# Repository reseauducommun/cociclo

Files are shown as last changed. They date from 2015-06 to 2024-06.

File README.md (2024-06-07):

# cociclo
An airborne particles, Carbon Monoxyde (CO), temperature and humidity sensor circuit based on the ESP8266 (Wemos).  One version sends data to mysql and allows for the exploration of visualisations.  The other turns the pollution levels into sound for a participatory walk. 

For more information about the art and activism project : https://artengine.ca/acastonguay

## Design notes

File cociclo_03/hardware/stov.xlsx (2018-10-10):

Stock | 2018-06-12
 | 50 | Wemos
AgitPOV
 | 100 + | plaquettes
 | 40 | batteries
 | 200 | chargeurs lipo
Cociclo
 | 50 | v. 0.3
 | 40 | v.02
 | 4 | v.0.4
 | 8 | MQ-7
 | 35 | DHT11

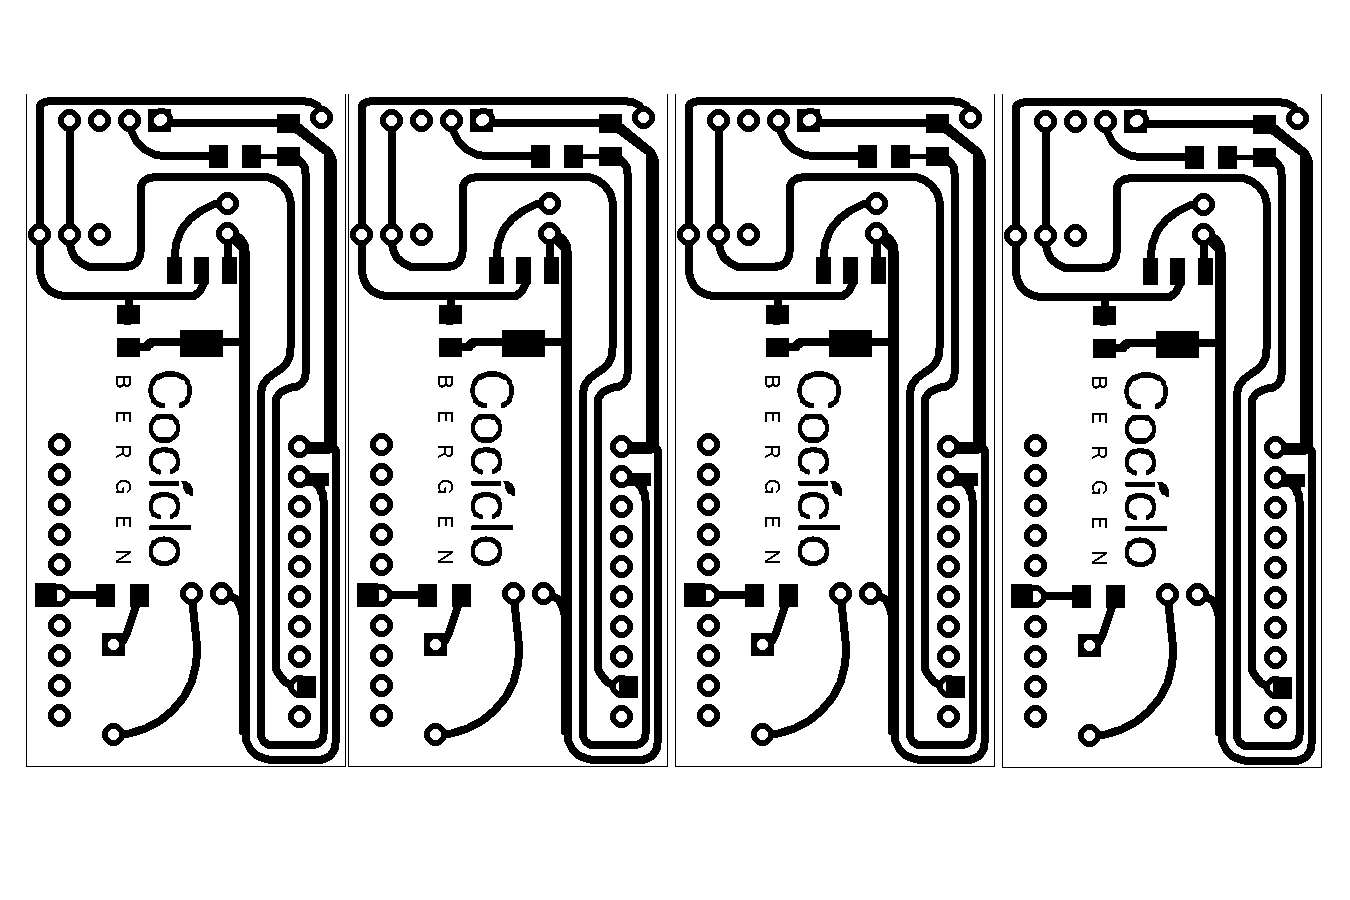
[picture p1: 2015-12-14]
cociclo_hardware/cociclo_bergen.png

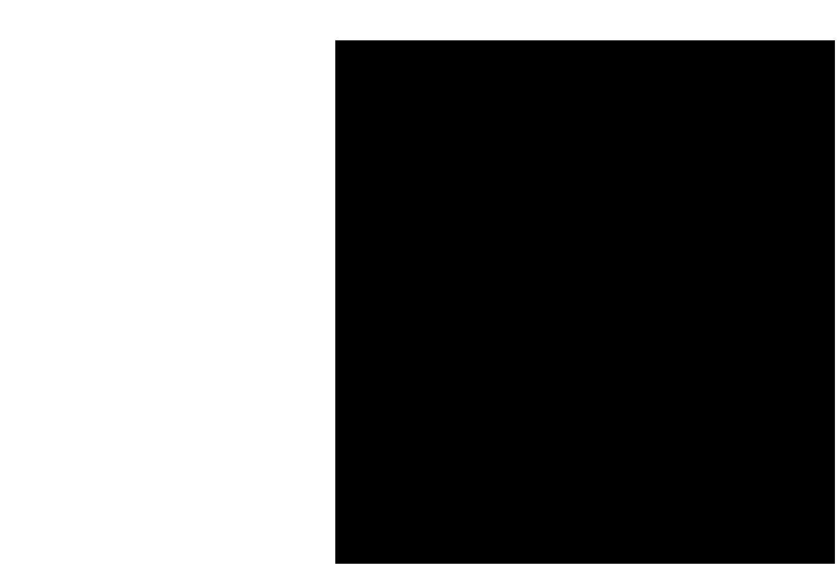
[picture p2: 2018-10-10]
cociclo_03/hardware/eagleUp/01/eagleUp_cociclo_03_imagesize.png

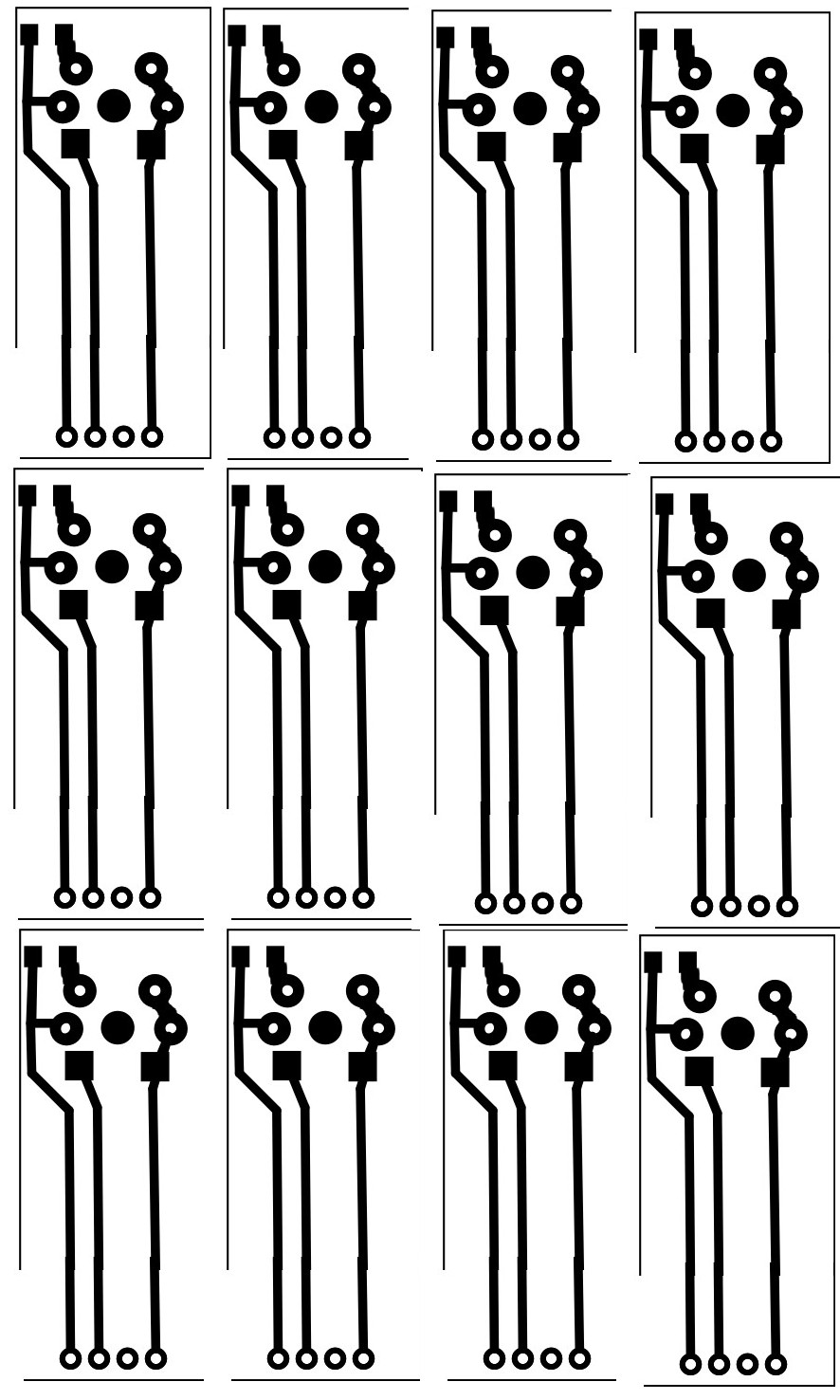
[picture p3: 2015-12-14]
cociclo_hardware/MQ7_impression.jpg

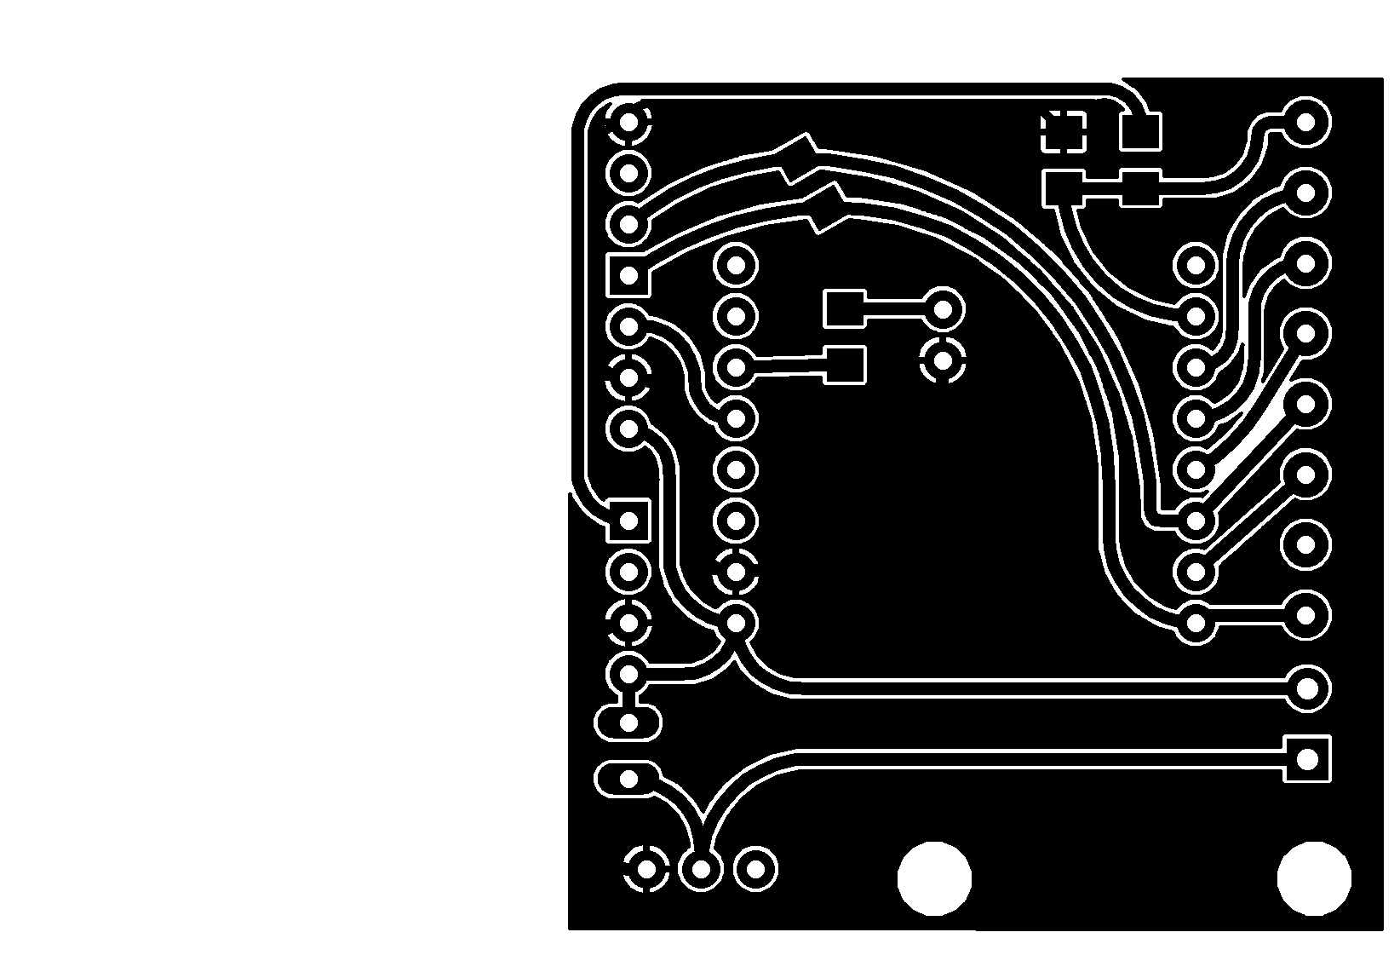
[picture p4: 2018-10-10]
cociclo_03/hardware/eagleUp/eagleUp_cociclo_03_bottom.png

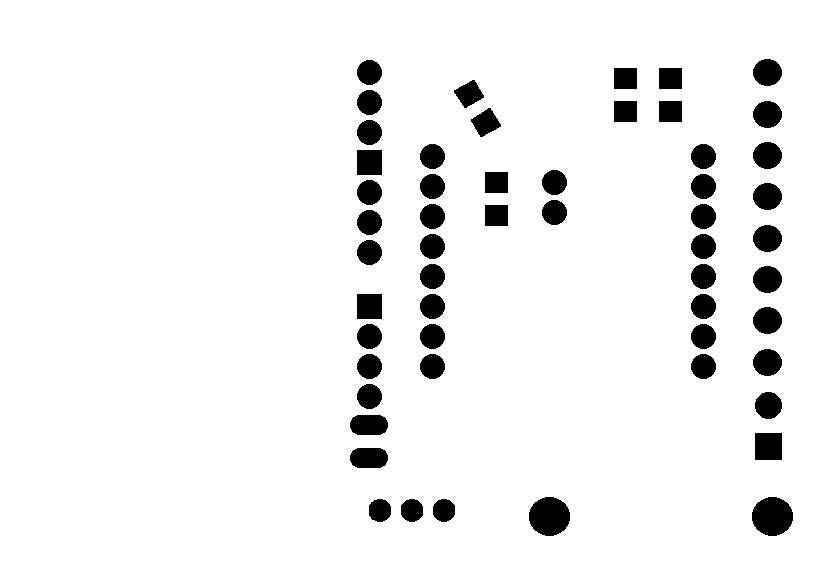
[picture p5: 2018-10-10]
cociclo_03/hardware/eagleUp/02/eagleUp_cociclo_03_bottom_mask.png

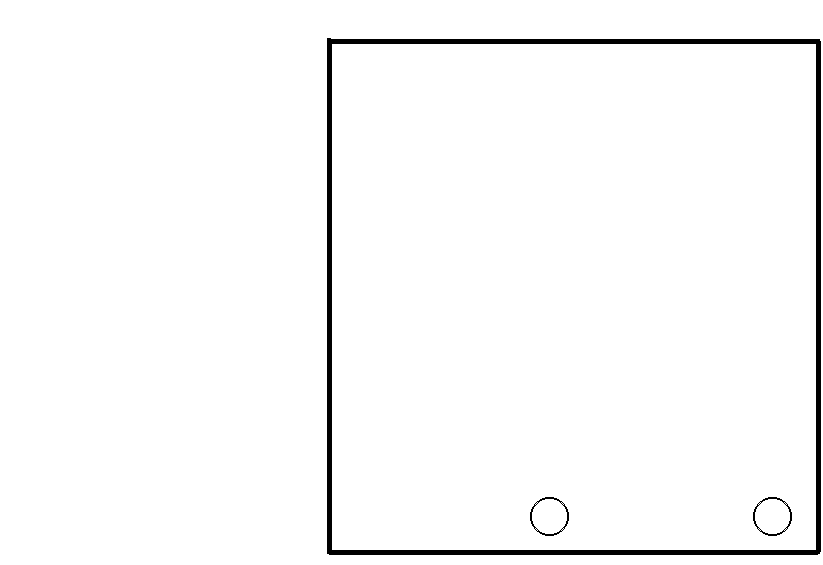
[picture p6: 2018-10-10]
cociclo_03/hardware/eagleUp/02/eagleUp_cociclo_03_outline.png

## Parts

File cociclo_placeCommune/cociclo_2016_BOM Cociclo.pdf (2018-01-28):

Cociclo

2016
Place

commune

Microcontroleur Huzzah

https://www.adafruit.com/products/2471144

USD

+

import | 15
Piezzo | Addison | 0
Plaquetas Artistes | anonymes Graveuse
UQAM | 2
Capteur

CO Mq_7

Sainsmart htp://www.sainsmart.com/sainsmart-‐mq7-‐co-‐carbon-‐monoxide-‐gas-‐sensor-‐module-‐for-‐arduino-‐uno-‐mega2560-‐r3.html 5
Résistances 2k | | 0,02
3k | 0,02
100

ohms http://www.digikey.com/product-‐detail/en/yageo/RC1206JR-‐07100RL/311-‐100ERCT-‐ND/732153 0,02
Chargeur

de

batterie http://www.ebay.com/itm/10pcs-‐Micro-‐USB-‐5V-‐1A-‐Lithium-‐Battery-‐Charging-‐Board-‐Charger-‐Module/370865460416?rt=nc&_soffid=5013240009&_soffType=OrderSubTotalOffer&_trksid=p5731.m3795 0,6 Capteur

de

Temp

et

Humidité DHT11 | http://www.alibaba.com/showroom/dht11-‐digital-‐temperature-‐and-‐humidity-‐sensor.html 300 | 100 | 3

Shipping

2
Total

27,66

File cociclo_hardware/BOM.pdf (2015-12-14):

Feuille1

## BOM

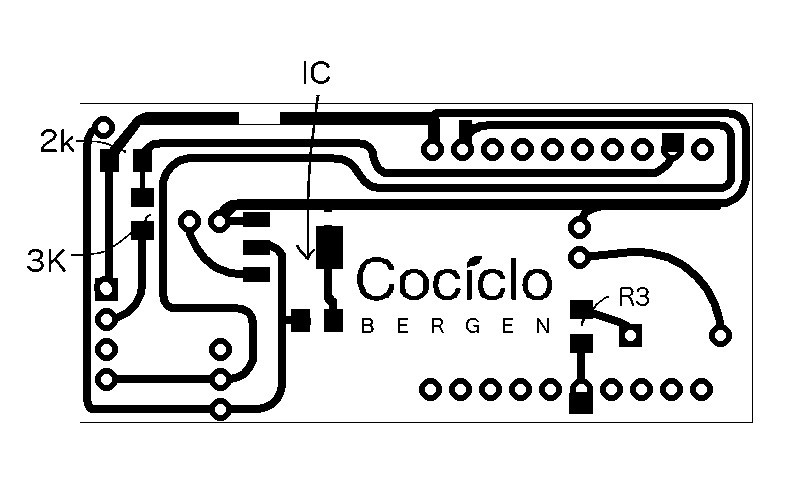
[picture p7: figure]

Name | Value | source

MQ7
LiPo battery charger (5v regulated output and micro USB input) | Ebay
IC | 5V 0.8A | IC REG LDO 5V 0.8A SOT223 497-6447-1-ND -
R1 | 2k ohms | RES SMD 2K OHM 5% 1/4W 1206 311-2.0KERCT-ND
R2 | 3k ohms | RES SMD 3K OHM 5% 1/4W 1206 311-3.0KERCT-ND
R3 | 100 ohms | RES SMD 100 OHM 1% 1/4W 1206 541-100FCT-ND
Switch
(Optional)
C | 10 uF Capacitor CAP CER 10UF 10V X5R 1206 445-1387-1-ND
B | Piezo buzzer

Case

## Cocíclo Bergen

part number

Cocíclo Bergen Board | Yours truly | see Eagle board
Huzzah from Adafruit | Adafruit | https://learn.adafruit.com/adafruit-huzzah-esp8266-breakout/overview
| Sainsmart | http://www.sainsmart.com/sainsmart-mq7-co-carbon-monoxide-gas-sensor-module-for-arduino-uno-mega2560-r3.html
| Digikey
| Digikey
| Digikey
| Digikey
| Yours truly
| Digikey
16 mm diameter
| Yours truly | see sketchup file (need to do it over in Blender)

Feuille1

https://learn.adafruit.com/adafruit-huzzah-esp8266-breakout/overviewhttp://www.sainsmart.com/sainsmart-mq7-co-carbon-monoxide-gas-sensor-module-for-arduino-uno-mega2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

see sketchup file (need to do it over in Blender)

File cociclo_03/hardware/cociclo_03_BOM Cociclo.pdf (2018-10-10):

Cociclo 03

Materiales proporcionados por el centro 1 5m cable (20-22 AWG, dos conductores, varado, exterior de color blanca, negra o azul)
1 Adaptadores (tipo móvil android 5V, micro USB) | este tipo :
1 Caja | | ver la archiva aquí, necesita una impresión 3D (lento!)
1 Bateria para rescargar móviles | este tipo :

Materiales proporcionados por el artista 1 Cajitas + velcro (en cartón para la caminada)
1 Bases de madera (cortador laser)
1 Microcontrôleur Wemos http://www.aliexpress.com/snapshot/7403403143.html?orderId=73408283519218
| | Shipping
1 Plaquetas Artistes anonymes Sart Prototyping / Seeed Studio | (payé Paypa)l
| | Shipping DHL + import taxes
1 Capteur CO | http://www.sainsmart.com/sainsmart-mq7-co-carbon-monoxide-gas-sensor-module-for-arduino-uno-mega2560-r3.html
1 Parlantes (buzzer) | Addison (surplus electronique) | este tipo http://www.banggood.com/PC-Computer-Motherboard-Interanal-BIOS-Alarm-Buzzer-Speaker-10pcs-p-967095.html
1 SK9822 Dotstar
1 Résistances 10k
1 | 2k
1 | 3k
1 | 100 ohms http://www.digikey.com/product-detail/en/yageo/RC1206JR-07100RL/311-100ERCT-ND/732153
1 Capteur de Temp et Humidité DHT11 | http://www.alibaba.com/showroom/dht11-digital-temperature-and-humidity-sensor.html
1 Capteur Plantower PMS3003https://www.aliexpress.com/item/Laser-PM2-5-DUST-SENSOR-PMS3003-High-precision-laser-dust-concentration-sensor-digital-dust-particles-G3/32371229255.html 1 Switch EG1903-ND https://www.digikey.ca/product-detail/en/e-switch/EG1218/EG1903-ND/101726
2 4 pos Pin header Female
5 2 pos screw terminal Borniers https://www.digikey.ca/product-detail/en/1776275-2/A98036-ND/1826899

Prix unitaire | Prix unitaire ($CAN)

http://ca.shopandroid.com/samsung-micro-usb-high-capacity-2a-travel-charger/5A17A14236.htm
ver la archiva aquí, necesita una impresión 3D (lento!) http://www.cdiscount.com/telephonie/accessoires-portable-gsm/powerbank-batterie-externe-portable-2600mah/f-144201603-gen2009967346433.html

0,5
0,5
4 USD | 5,06
2
111,73 | 1,12 CAN | 1,12
48,96 | 0,49 | 0,49

GearBest
GearBest | 312,73 | 3,91
Taxes importation | 37,6 | 0,47
este tipo http://www.banggood.com/PC-Computer-Motherboard-Interanal-BIOS-Alarm-Buzzer-Speaker-10pcs-p-967095.html 1 0,75
0,02
0,02
0,02
0,02
250 | 100 CAN | 2,5
15 USD | 20 CAN | 20 ** Optionnel
1 CAN | 1
0
0,45 | 2,25
Total | 38,38

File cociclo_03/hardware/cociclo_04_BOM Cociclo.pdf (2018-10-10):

Cociclo 04.1

Prix unitaire Prix unitaire ($CAN) Materiales proporcionados por el artista
1 Caja (boitier) | ver la archiva aquí, necesita una impresión 3D (lento!) | 6
1 Soudure de surface | 3
1 Chargeur cube | 2
1 Câble USB long | 2
1 Bases de madera (cortador laser) | 0,5
1 Microcontrôleur Wemos http://www.aliexpress.com/snapshot/7403403143.html?orderId=73408283519218 4 USD | 5,06
Shipping | 2
1 Plaquetas Artistes anonymes Smart Prototyping / Seeed Studio (payé Paypa)l | 111,73 1,12 CAN | 1,12
Shipping DHL + import taxes 48,96 0,49 | 0,49
1 Capteur CO | http://www.sainsmart.com/sainsmart-mq7-co-carbon-monoxide-gas-sensor-module-for-arduino-uno-mega2560-r3.html GearBest
GearBest | 312,73 | 3,91
Taxes importation37,6 | 0,47
1 SK9822 Dotstar | 0,75
1 Résistances 10k | 0,02
1 | 2k | 0,02
1 | 3k | 0,02
1 Capteur de Temp et Humidité DHT11 http://www.alibaba.com/showroom/dht11-digital-temperature-and-humidity-sensor.html 250 | 100 CAN | 2,5
1 Capteur Plantower PMS7003 https://www.aliexpress.com/item/Laser-PM2-5-DUST-SENSOR-PMS3003-High-precision-laser-dust-concentration-sensor-digital-dust-particles-G3/32371229255.html 15 USD | 20 CAN
Total | 29,86

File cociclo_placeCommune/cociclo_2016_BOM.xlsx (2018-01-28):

Cociclo 2016
Place commune
 |  |  |  |  | Prix unitaire |  | Prix unitaire CAN
Microcontroleur | Huzzah | https://www.adafruit.com/products/2471 | 144 USD + import | 134.4 | 8.96 | USD | 11.33
 |  |  | Shipping | 27.97 | 1.86 | USD | 2.36
 |  |  | Taxes importation | 14 | 0.93 | CAN | 0.93
Plaquetas | Artistes anonymes | Graveuse UQAM |  | 2 |  |  | 2
Capteur CO | Mq_7 Sainsmart | http://www.sainsmart.com/sainsmart-mq7-co-carbon-monoxide-gas-sensor-module-for-arduino-uno-mega2560-r3.html |  |  |  |  | 5
Résistances | 2k |  |  |  |  |  | 0.02
 | 3k |  |  |  |  |  | 0.02
 | 100 ohms | http://www.digikey.com/product-detail/en/yageo/RC1206JR-07100RL/311-100ERCT-ND/732153 |  |  |  |  | 0.02
Chargeur de batterie |  | http://www.ebay.com/itm/10pcs-Micro-USB-5V-1A-Lithium-Battery-Charging-Board-Charger-Module/370865460416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 |  |  |  |  | 0.6
Capteur de Temp et Humidité | DHT11 | http://www.alibaba.com/showroom/dht11-digital-temperature-and-humidity-sensor.html |  | 300 | 100 | CAN | 3
 |  |  | Shipping | 150 |  |  | 1.5
 |  |  |  |  |  | Total | 26.79

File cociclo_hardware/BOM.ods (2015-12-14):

Cocíclo Bergen |  | BOM
 | Name | Value |  | part number | source
 | Cocíclo Bergen Board |  |  |  | Yours truly | see Eagle board
 | Huzzah from Adafruit |  |  |  | Adafruit | https://learn.adafruit.com/adafruit-huzzah-esp8266-breakout/overview
 | MQ7 |  |  |  | Sainsmart | http://www.sainsmart.com/sainsmart-mq7-co-carbon-monoxide-gas-sensor-module-for-arduino-uno-mega2560-r3.html
 | LiPo battery charger (5v regulated output and micro USB input) |  |  |  | Ebay
 | IC | 5V 0.8A | IC REG LDO 5V 0.8A SOT223 | 497-6447-1-ND - | Digikey
 | R1 | 2k ohms | RES SMD 2K OHM 5% 1/4W 1206 | 311-2.0KERCT-ND | Digikey
 | R2 | 3k ohms | RES SMD 3K OHM 5% 1/4W 1206 | 311-3.0KERCT-ND | Digikey
 | R3 | 100 ohms | RES SMD 100 OHM 1% 1/4W 1206 | 541-100FCT-ND | Digikey
 | Switch |  |  |  | Yours truly
 | (Optional)
 | C | 10 uF Capacitor | CAP CER 10UF 10V X5R 1206 | 445-1387-1-ND | Digikey
 | B | Piezo buzzer | 16 mm diameter
 | Case |  |  |  | Yours truly | see sketchup file (need to do it over in Blender)

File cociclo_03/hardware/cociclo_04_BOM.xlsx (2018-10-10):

Cociclo 04.1
 |  |  |  |  |  |  |  | Prix unitaire ($CAN) | coût de fabrication | FabLabduPec
Cociclo station
1 | Caja (boitier) |  |  | ver la archiva aquí, necesita una impresión 3D (lento!) |  |  |  | 3 | 3 | 3
1 | Soudure de surface |  |  |  |  |  |  | 0 | 3
1 | Chargeur cube |  |  |  |  |  |  | 2
1 | Câble USB long |  |  |  |  |  |  | 2
1 | Bases de madera (cortador laser) |  |  |  |  |  |  |  | 0.5 | 0.5
1 | Microcontrôleur Wemos |  | http://www.aliexpress.com/snapshot/7403403143.html?orderId=73408283519218 |  |  | 4 | USD | 5.06
 |  |  |  | Shipping |  |  |  | 2
1 | Plaquetas | Artistes anonymes | Smart Prototyping / Seeed Studio | (payé Paypa)l | 111.73 | 1.12 | CAN | 1.12
 |  |  |  | Shipping DHL + import taxes | 48.96 | 0.49 |  | 0.49
1 | Capteur CO |  | http://www.sainsmart.com/sainsmart-mq7-co-carbon-monoxide-gas-sensor-module-for-arduino-uno-mega2560-r3.html |  | GearBest
 |  |  |  |  |  | GearBest | 312.73 | 3.91
 |  |  |  |  |  | Taxes importation | 37.6 | 0.47
1 | SK9822 Dotstar |  |  |  |  |  |  | 0.75
1 | Résistances | 10k |  |  |  |  |  | 0.02
1 |  | 2k |  |  |  |  |  | 0.02
1 |  | 3k |  |  |  |  |  | 0.02
1 | Capteur de Temp et Humidité | DHT11 | http://www.alibaba.com/showroom/dht11-digital-temperature-and-humidity-sensor.html |  | 250 | 100 | CAN | 2.5
1 | Capteur Plantower PMS7003 |  | https://www.aliexpress.com/item/Laser-PM2-5-DUST-SENSOR-PMS3003-High-precision-laser-dust-concentration-sensor-digital-dust-particles-G3/32371229255.html |  | 15 USD | 20 | CAN
 |  |  |  |  |  |  | Total | 23.36 | 6.5 | 3.5
Cociclo audio |  |  |  |  |  |  |  | Prix unitaire ($CAN) | coût de fabrication | FabLabduPec
1 | boitier de carton |  |  |  |  |  |  | 1 | 1 | 1
1 | Soudure de surface |  |  |  |  |  |  |  | 3
1 | Microcontrôleur Wemos |  | http://www.aliexpress.com/snapshot/7403403143.html?orderId=73408283519218 |  |  | 4 | USD | 5.06
 |  |  |  | Shipping |  |  |  | 2
1 | Plaquetas | Artistes anonymes | Smart Prototyping / Seeed Studio | (payé Paypa)l | 111.73 | 1.12 | CAN | 1.12
 |  |  |  | Shipping DHL + import taxes | 48.96 | 0.49 |  | 0.49
1 | Batterie rechargeable |  |  | 3.7V LiPO |  |  |  | 2
1 | Capteur CO |  | http://www.sainsmart.com/sainsmart-mq7-co-carbon-monoxide-gas-sensor-module-for-arduino-uno-mega2560-r3.html |  | GearBest
 |  |  |  |  |  | GearBest | 312.73 | 3.91
 |  |  |  |  |  | Taxes importation | 37.6 | 0.47
1 | Résistances | 10k |  |  |  |  |  | 0.02
1 |  | 2k |  |  |  |  |  | 0.02
1 |  | 3k |  |  |  |  |  | 0.02
1 | Capteur de Temp et Humidité | DHT11 | http://www.alibaba.com/showroom/dht11-digital-temperature-and-humidity-sensor.html |  | 250 | 100 | CAN | 2.5
1 | Piezzo |  |  |  |  |  |  | 1
1 | Switch |  |  |  |  |  |  | 1
1 | pinheaders |  |  |  |  |  |  | 0.25
2 | Câbles board to board |  |  |  |  |  |  | 0.5
 |  |  |  |  |  |  | Total | 21.36 | 4 | 1

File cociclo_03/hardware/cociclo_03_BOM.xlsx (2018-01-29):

Cociclo 03
 |  |  |  |  |  | Prix unitaire |  | Prix unitaire ($CAN)
Materiales proporcionados por el centro
1 | 5m cable (20-22 AWG, dos conductores, varado, exterior de color blanca, negra o azul)
1 | Adaptadores (tipo móvil android 5V, micro USB) |  |  | este tipo : | http://ca.shopandroid.com/samsung-micro-usb-high-capacity-2a-travel-charger/5A17A14236.htm
1 | Caja |  |  | ver la archiva aquí, necesita una impresión 3D (lento!)
1 | Bateria para rescargar móviles |  |  | este tipo : | http://www.cdiscount.com/telephonie/accessoires-portable-gsm/powerbank-batterie-externe-portable-2600mah/f-144201603-gen2009967346433.html
Materiales proporcionados por el artista
1 | Cajitas + velcro (en cartón para la caminada) |  |  |  |  |  |  | 0.5
1 | Bases de madera (cortador laser) |  |  |  |  |  |  | 0.5
1 | Microcontrôleur Wemos |  | http://www.aliexpress.com/snapshot/7403403143.html?orderId=73408283519218 |  |  | 4 | USD | 5.06
 |  |  |  | Shipping |  |  |  | 2
1 | Plaquetas | Artistes anonymes | Smart Prototyping / Seeed Studio | (payé Paypa)l | 111.73 | 1.12 | CAN | 1.12
 |  |  |  | Shipping DHL + import taxes | 48.96 | 0.49 |  | 0.49
1 | Capteur CO |  | http://www.sainsmart.com/sainsmart-mq7-co-carbon-monoxide-gas-sensor-module-for-arduino-uno-mega2560-r3.html |  | GearBest
 |  |  |  |  |  | GearBest | 312.73 | 3.91
 |  |  |  |  |  | Taxes importation | 37.6 | 0.47
1 | Parlantes (buzzer) |  | Addison (surplus electronique) | este tipo http://www.banggood.com/PC-Computer-Motherboard-Interanal-BIOS-Alarm-Buzzer-Speaker-10pcs-p-967095.html |  |  |  | 1
1 | SK9822 Dotstar |  |  |  |  |  |  | 0.75
1 | Résistances | 10k |  |  |  |  |  | 0.02
1 |  | 2k |  |  |  |  |  | 0.02
1 |  | 3k |  |  |  |  |  | 0.02
1 |  | 100 ohms | http://www.digikey.com/product-detail/en/yageo/RC1206JR-07100RL/311-100ERCT-ND/732153 |  |  |  |  | 0.02
1 | Capteur de Temp et Humidité | DHT11 | http://www.alibaba.com/showroom/dht11-digital-temperature-and-humidity-sensor.html |  | 250 | 100 | CAN | 2.5
1 | Capteur Plantower PMS3003 |  | https://www.aliexpress.com/item/Laser-PM2-5-DUST-SENSOR-PMS3003-High-precision-laser-dust-concentration-sensor-digital-dust-particles-G3/32371229255.html |  | 15 USD | 20 | CAN | 20 | ** Optionnel
1 | Switch | EG1903-ND | https://www.digikey.ca/product-detail/en/e-switch/EG1218/EG1903-ND/101726 |  |  | 1 | CAN | 1
2 | 4 pos Pin header Female |  |  |  |  |  |  | 0
5 | 2 pos screw terminal Borniers |  | https://www.digikey.ca/product-detail/en/1776275-2/A98036-ND/1826899 |  |  | 0.45 |  | 2.25
 |  |  |  |  |  |  | Total | 38.38

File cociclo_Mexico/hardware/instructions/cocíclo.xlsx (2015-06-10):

Cocíclo BOM
Identifiant | Type | Valor | Digikey part #
R1 | Resistencia | 330 ohms
R2, R3, R5 | Resistencias | 10k ohms
R4 | Resistencia | 390 ohms
C1,C2 | Condensatores | 10 uF | PCE3394CT-ND
C3 | Condensatore | 1 nf
LED 1 | LED | indicator
LED2 | LED through hole | tri-color
REG | Régulateur de tension | 5V | TA4805BF(T6L1NQ)CT-ND
S1 | Interruptor
Pila | Cable | 9V
Audio | Cable | audio
Barquetta | 28 pins
ATMEGA168PU | Microcontroller | uC | ATMEGA168A-PU-ND
MH-7 | Capteur | CO
Opcional
R6 | resistancia | 10k ohms
R7 | Photoresistor | 2-80k ohms
À évaluer : | http://www.cdiweb.com/ProductDetail/MICS4514-e2v/333417/#.VXhzC1V_NBc

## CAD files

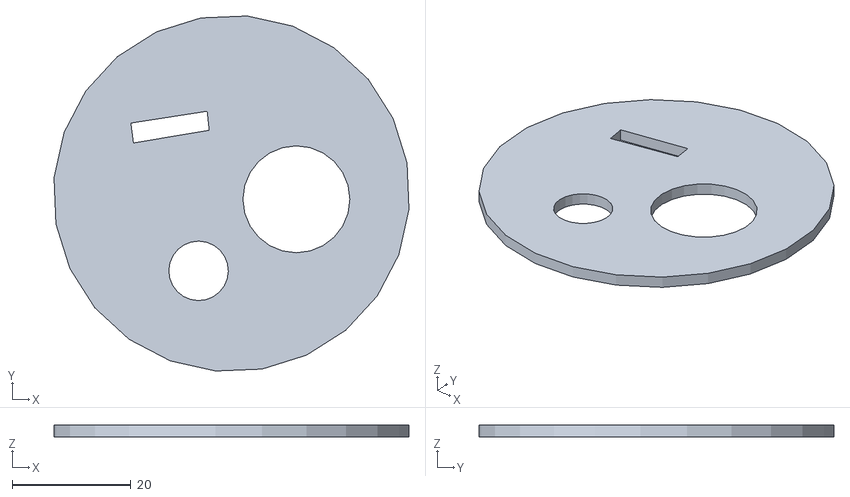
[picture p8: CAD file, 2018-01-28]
cociclo_placeCommune/boitier/fond_cociclo_wemos.stl
59.8 x 59.8 x 2.00

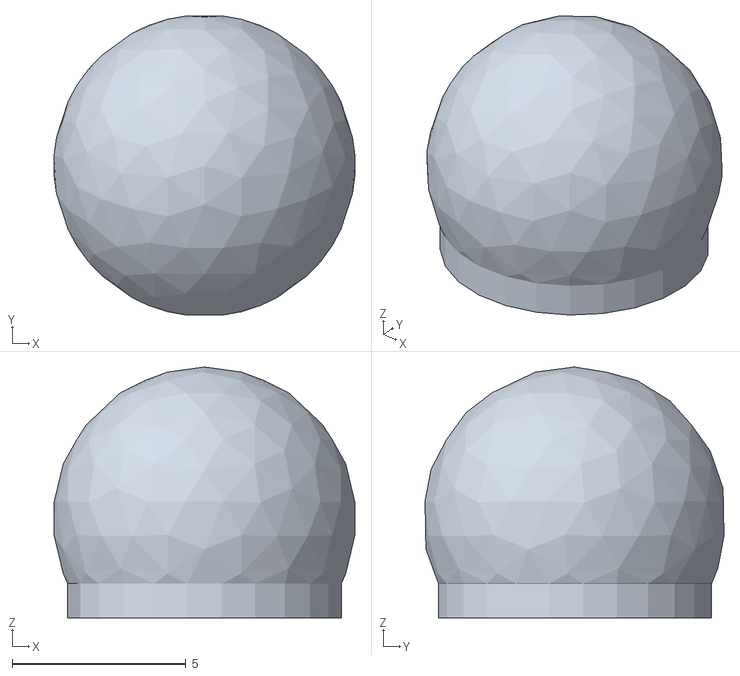
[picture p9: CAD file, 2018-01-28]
cociclo_transpiksel_eastern_bloc/hardware/radome avec base.stl
8.66 x 8.61 x 7.22

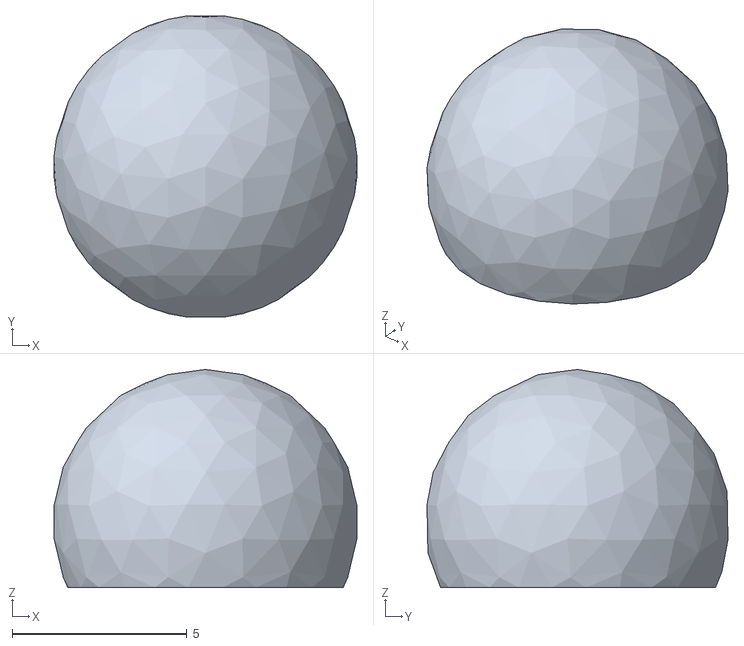
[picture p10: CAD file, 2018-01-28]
cociclo_transpiksel_eastern_bloc/hardware/radome.stl
8.66 x 8.61 x 6.24

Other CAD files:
cociclo_Mexico/hardware/case/boitier_01_base.skp
cociclo_Mexico/hardware/case/boitier_01_couvercle.skp
cociclo_placeCommune/boitier/EnregistrementAuto_cociclo_fond.skp
cociclo_placeCommune/boitier/cociclo_fond.skp

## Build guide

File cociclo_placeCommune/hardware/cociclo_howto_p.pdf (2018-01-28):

Le!contenu!des!kits :!

Plaquette!Cocíclo!Santropol!(les!résistances!sont!déjà!soudées) Un!Huzzah!(https://learn.adafruit.com/adafruitDhuzzahDesp8266Dbreakout/overview) Capteur!de!Monoxyde!de!Carbone!MQD7
Capteur!de!température!et!d’humidité DHTD22
3!broches!D réceptacles!à!4!posisitions
fil!noir
Une!borne!à!deux!positions Un!connecteur!microDUSB

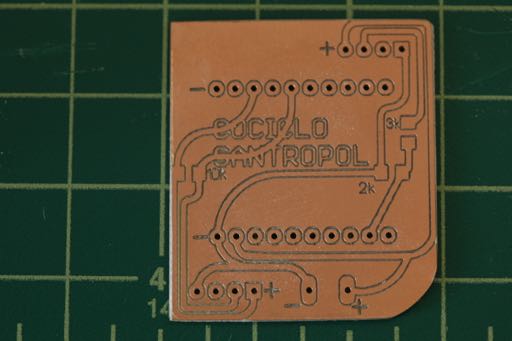
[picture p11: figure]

cc

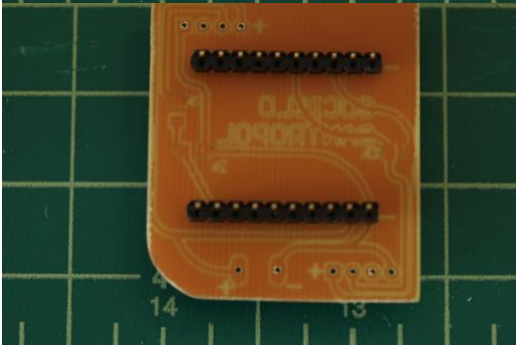
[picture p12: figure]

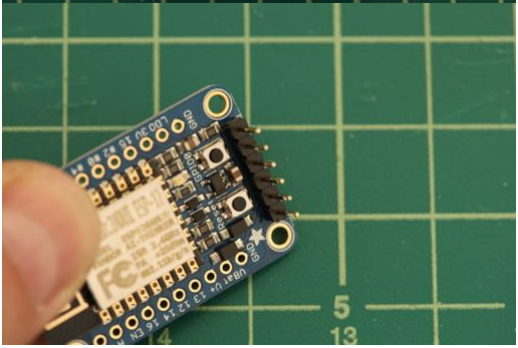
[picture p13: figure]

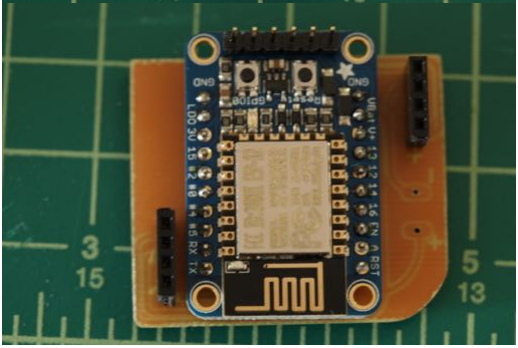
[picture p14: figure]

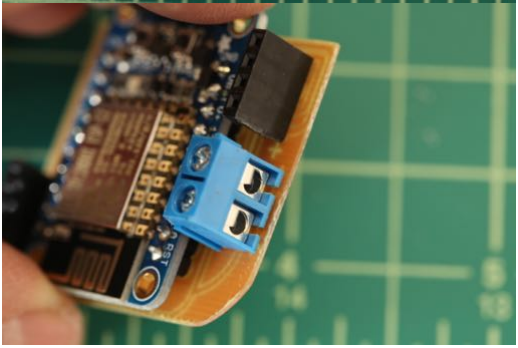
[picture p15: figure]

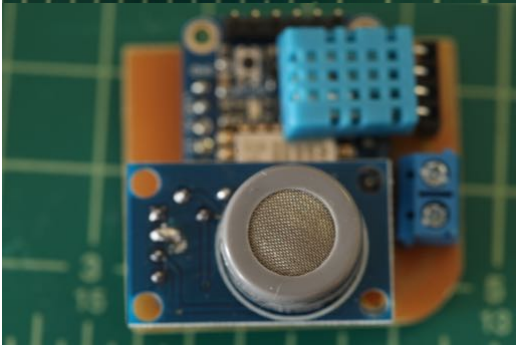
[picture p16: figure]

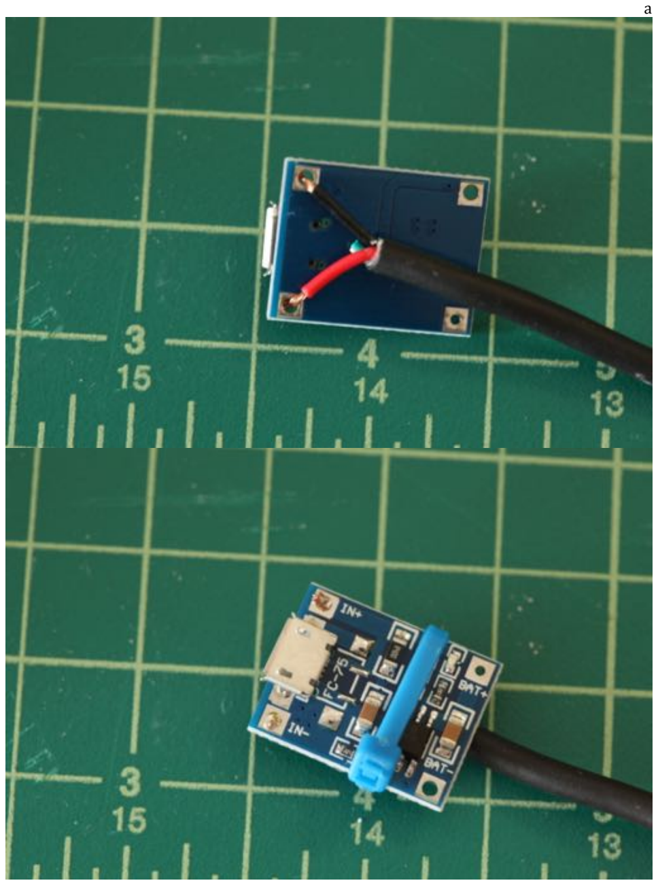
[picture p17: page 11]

a

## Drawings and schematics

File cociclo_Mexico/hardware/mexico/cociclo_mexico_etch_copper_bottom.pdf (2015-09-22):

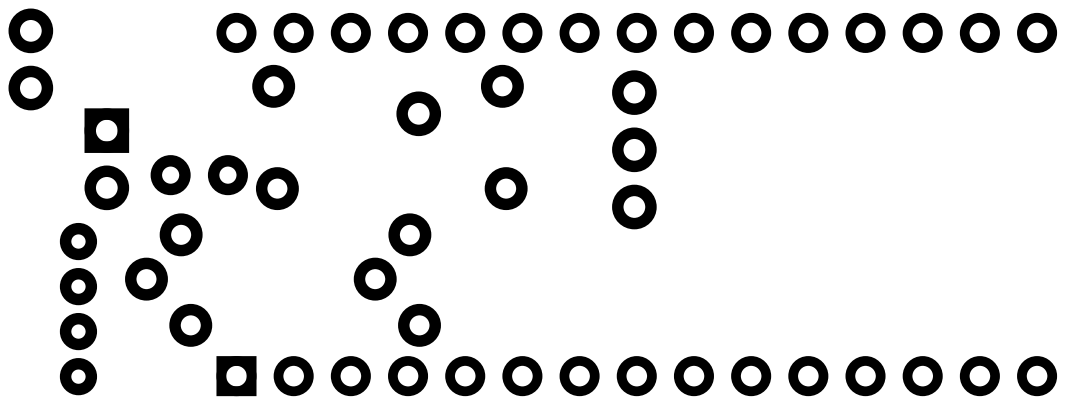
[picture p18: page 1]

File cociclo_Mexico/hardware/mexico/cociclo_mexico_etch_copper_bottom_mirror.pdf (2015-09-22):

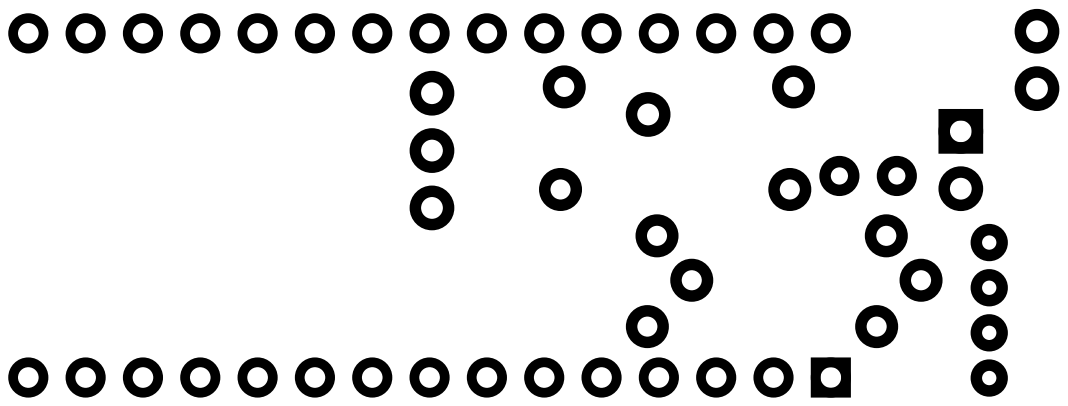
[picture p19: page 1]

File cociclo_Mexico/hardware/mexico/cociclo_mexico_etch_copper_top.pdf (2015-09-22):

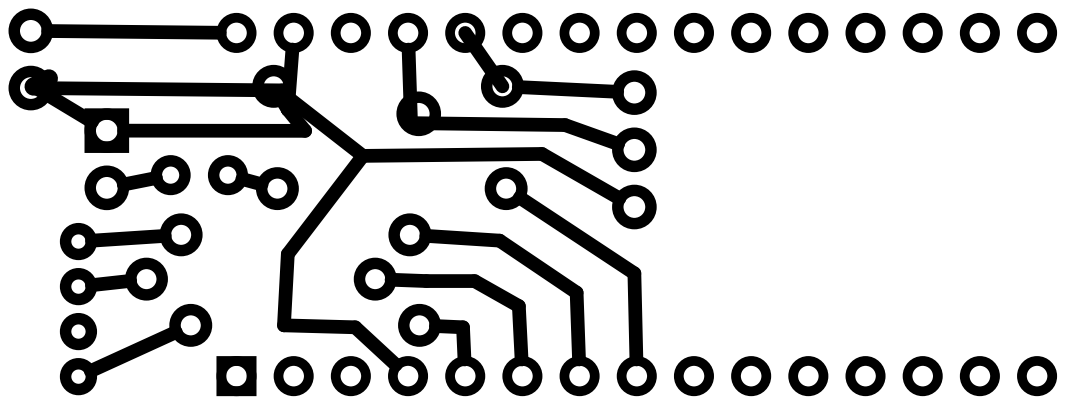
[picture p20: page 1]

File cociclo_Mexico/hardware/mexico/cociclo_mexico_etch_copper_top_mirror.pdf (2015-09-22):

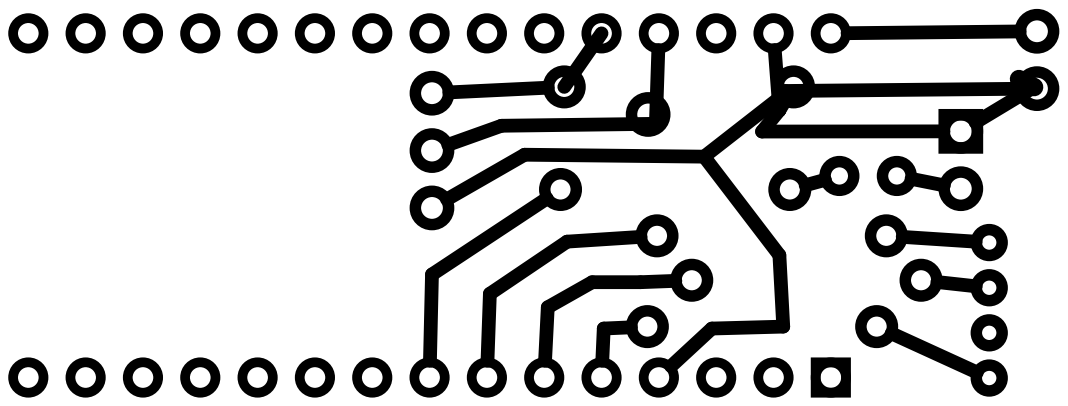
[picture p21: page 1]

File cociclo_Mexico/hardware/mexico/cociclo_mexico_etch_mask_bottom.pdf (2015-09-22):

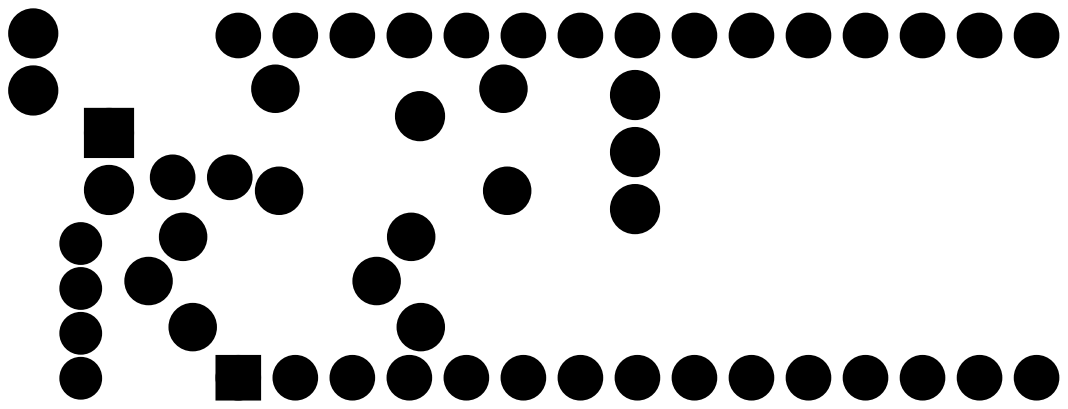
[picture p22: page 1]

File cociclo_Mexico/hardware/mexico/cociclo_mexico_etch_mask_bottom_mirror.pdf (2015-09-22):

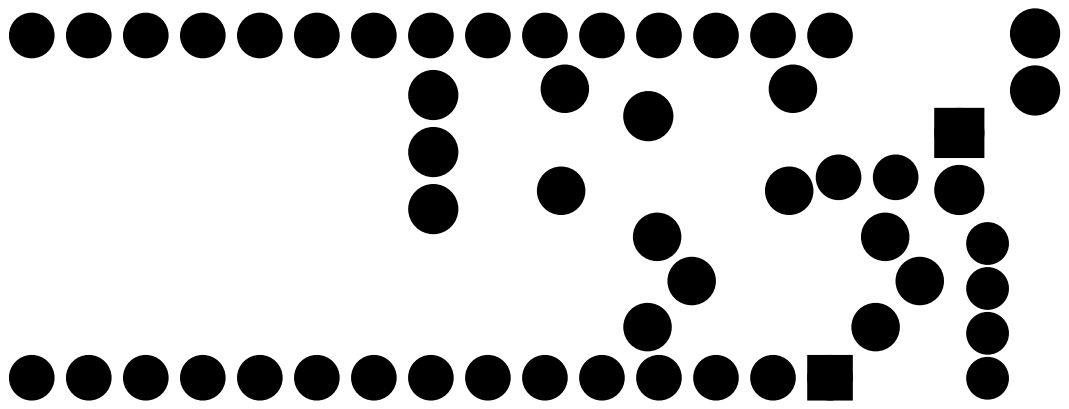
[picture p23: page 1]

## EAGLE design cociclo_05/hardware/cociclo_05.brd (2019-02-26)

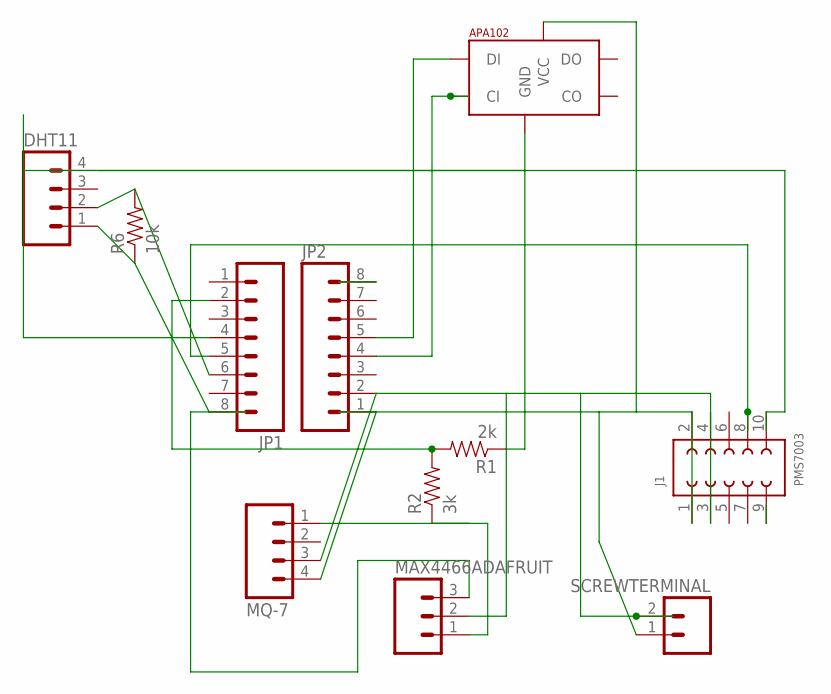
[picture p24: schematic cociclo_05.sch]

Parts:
DHT11: M04PTH; 1X04
J1: PMS7003; 621X1021021
JP1, JP2: M08; 1X08_ROUND
MAX4466ADAFRUIT: M03PTH; 1X03
MQ-7: M04PTH; 1X04
R1: 2k; 1206
R2: 3k; 1206
R6: 10k; 1206
SCREWTERMINAL: M023.5MM; SCREWTERMINAL-3.5MM-2
SK9822LED: APA1025050; APA102_5050

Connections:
7RX: J1.8 (7), JP1.5
9TX: J1.10 (6), JP1.4
10SET: J1.9 (5)
+5V: J1.1, J1.2 (10), JP2.1, MQ-7.4, SCREWTERMINAL.1, SK9822LED.1 (VCC)
ADC: JP1.2, R1.2, R2.2
CH_PD: DHT11.1, JP1.8, MAX4466ADAFRUIT.3, R6.1
D2: JP2.5, SK9822LED.4 (DI)
GND: DHT11.4, J1.3 (2), J1.4 (9), JP2.2, MAX4466ADAFRUIT.2, MQ-7.3, R1.1, SCREWTERMINAL.2, SK9822LED.6 (GND)
GPIO14: DHT11.2, JP1.6, R6.2
MQ7ANALOG: MAX4466ADAFRUIT.1, MQ-7.1, R2.1
unnamed: JP2.4, SK9822LED.5 (CI)

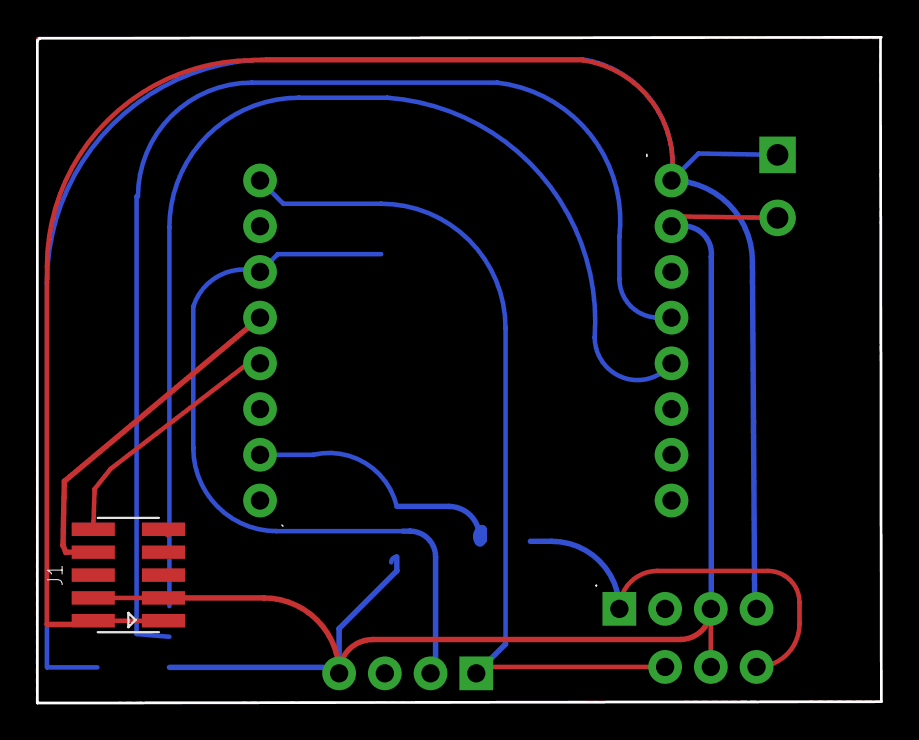
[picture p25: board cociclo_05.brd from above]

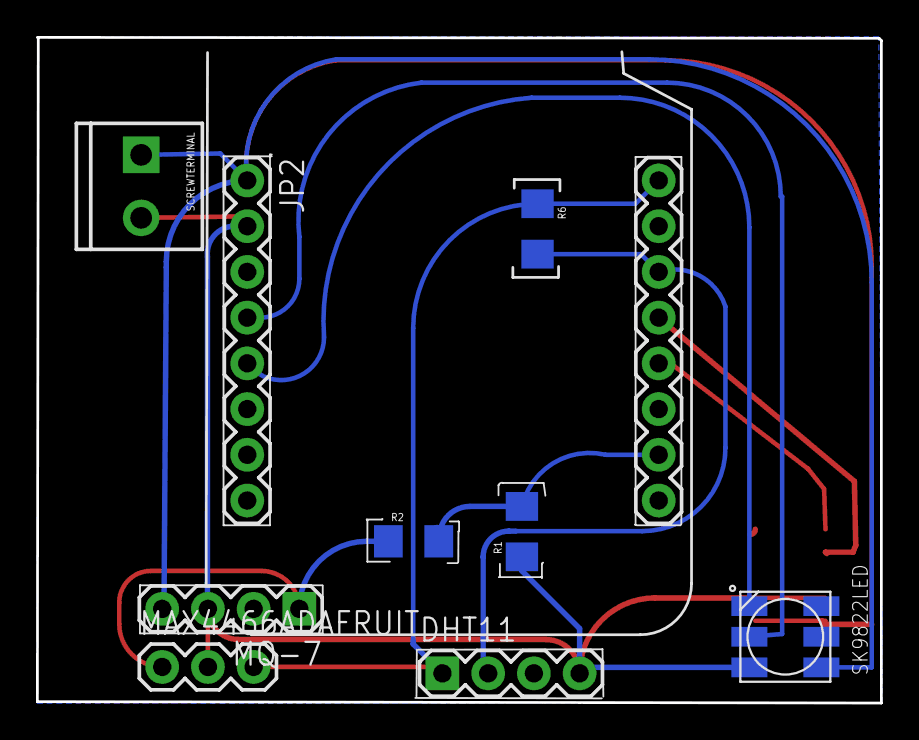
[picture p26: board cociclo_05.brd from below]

Board: 2 copper layers, 46.9 x 37.0 mm, 11 parts (10 on the bottom side), 10 nets.

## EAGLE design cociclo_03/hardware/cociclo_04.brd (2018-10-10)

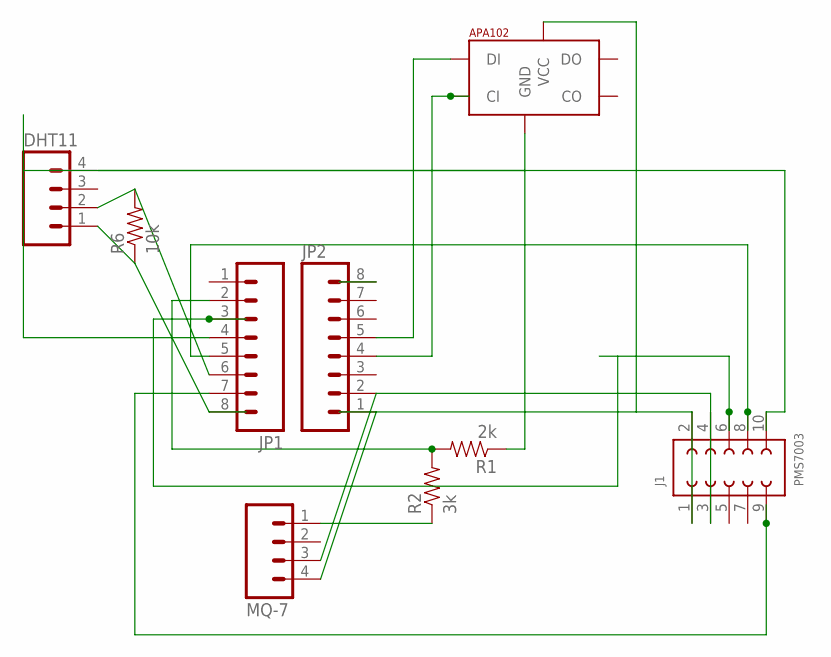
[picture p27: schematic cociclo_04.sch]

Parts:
DHT11: M04PTH; 1X04
J1: PMS7003; 621X1021021
JP1, JP2: M08; 1X08_ROUND
LED: APA1025050; APA102_5050
MQ-7: M04PTH; 1X04
R1: 2k; 1206
R2: 3k; 1206
R6: 10k; 1206

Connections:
5RESET: J1.6 (8), JP1.3
7RX: J1.8 (7), JP1.5
9TX: J1.10 (6), JP1.4
10SET: J1.9 (5), JP1.7
+5V: J1.1, J1.2 (10), JP2.1, LED.1 (VCC), MQ-7.4
ADC: JP1.2, R1.2, R2.2
CH_PD: DHT11.1, JP1.8, R6.1
D2: JP2.5, LED.4 (DI)
GND: DHT11.4, J1.3 (2), J1.4 (9), JP2.2, LED.6 (GND), MQ-7.3, R1.1
GPIO14: DHT11.2, JP1.6, R6.2
MQ7ANALOG: MQ-7.1, R2.1
unnamed: JP2.4, LED.5 (CI)

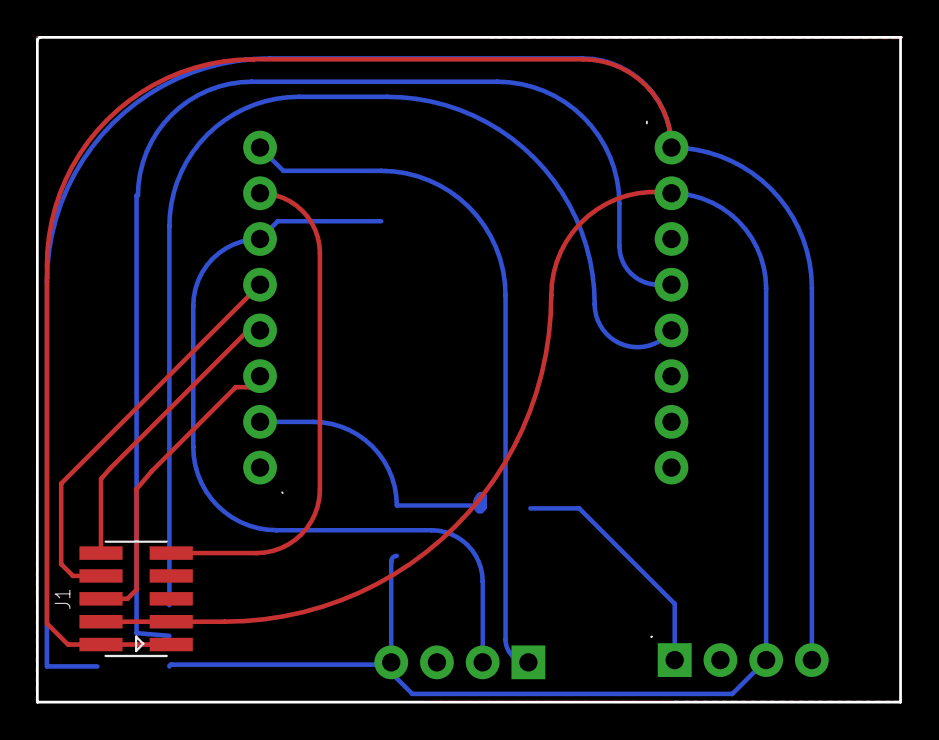
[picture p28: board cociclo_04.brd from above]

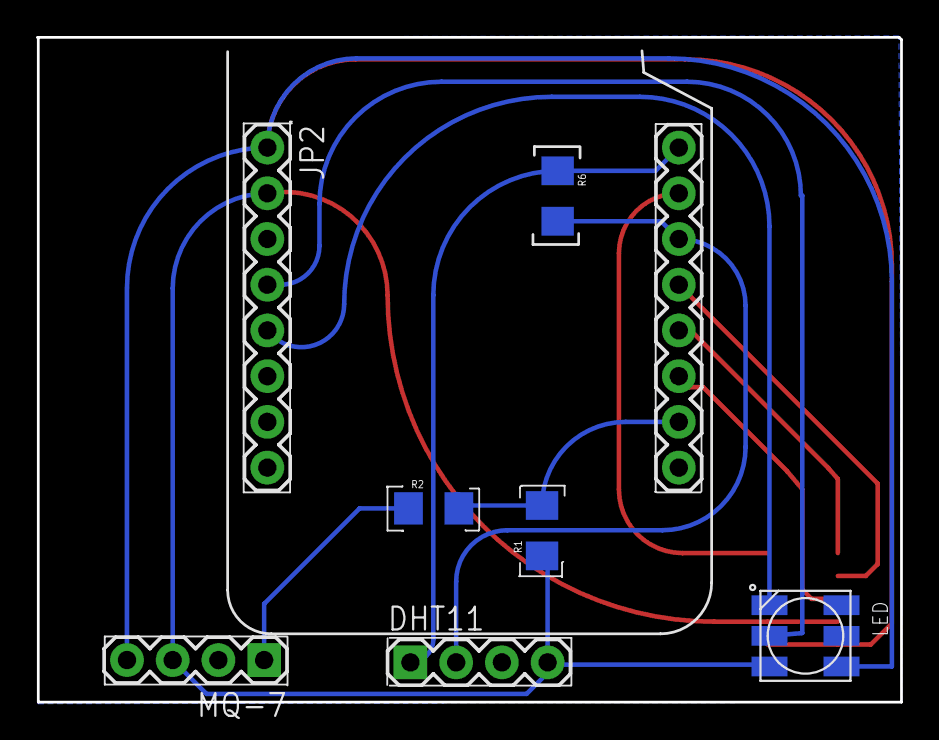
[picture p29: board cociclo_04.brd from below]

Board: 2 copper layers, 48.0 x 36.9 mm, 9 parts (8 on the bottom side), 12 nets.

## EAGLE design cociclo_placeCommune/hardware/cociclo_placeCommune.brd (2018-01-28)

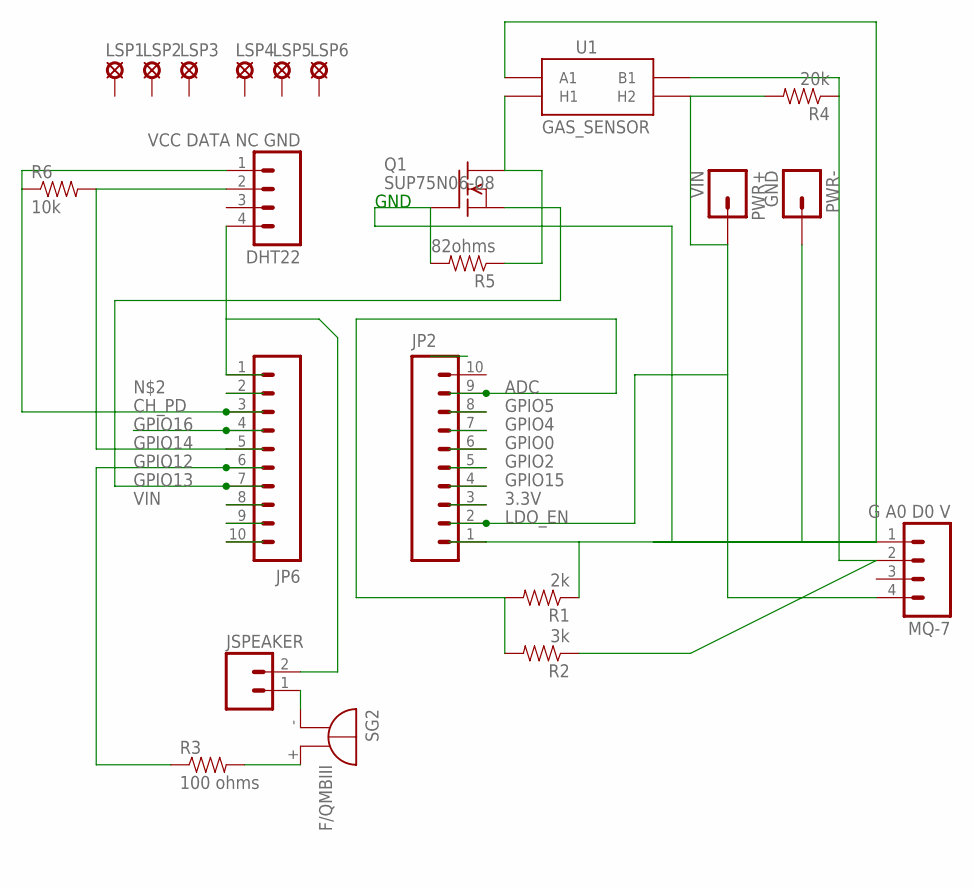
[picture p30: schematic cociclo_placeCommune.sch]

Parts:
DHT22: VCC DATA NC GND; 1X04
JP2, JP6: M10SILK_FEMALE_PTH; 1X10
JSPEAKER: M02PTH; 1X02
LSP1, LSP2, LSP3, LSP4, LSP5, LSP6: LSP10
MQ-7: G A0 D0 V; 1X04
PWR+: VIN; 1X01NS-KIT
PWR-: GND; 1X01NS-KIT
Q1: SUP75N06-08; TO220
R1: 2k; 1206
R2: 3k; 1206
R3: 100 ohms; 1206
R4: 20k; 1206
R5: 82ohms; 1206
R6: 10k; 1206
SG2: F/QMBIII
U1: GAS_SENSOR; MQ-3

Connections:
3.3V: JP2.3
ADC: JP2.9, R1.2, R2.2
CH_PD: DHT22.1, JP6.3, R6.1
GND: JP2.1, JP6.10, MQ-7.1, PWR-.1, Q1.1 (G), R1.1, R5.2, U1.A1
GPIO0: JP2.6
GPIO2: JP2.5
GPIO4: JP2.7
GPIO5: JP2.8
GPIO12: JP6.6, R3.1
GPIO13: JP6.7, Q1.3 (S)
GPIO14: DHT22.2, JP6.5, R6.2
GPIO15: JP2.4
GPIO16: JP6.4
LDO_EN: JP2.2, MQ-7.4, PWR+.1, R4.2, U1.HB (H2)
unnamed: MQ-7.2, R2.1, R4.1, U1.B1
unnamed: R3.2, SG2.+ (-)
unnamed: JSPEAKER.1, SG2.- (+)
unnamed: Q1.2 (D), R5.1, U1.HA (H1)
RESET_5V: DHT22.4, JP6.1, JSPEAKER.2
VBAT: JP6.9
VIN: JP6.8

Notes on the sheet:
GND

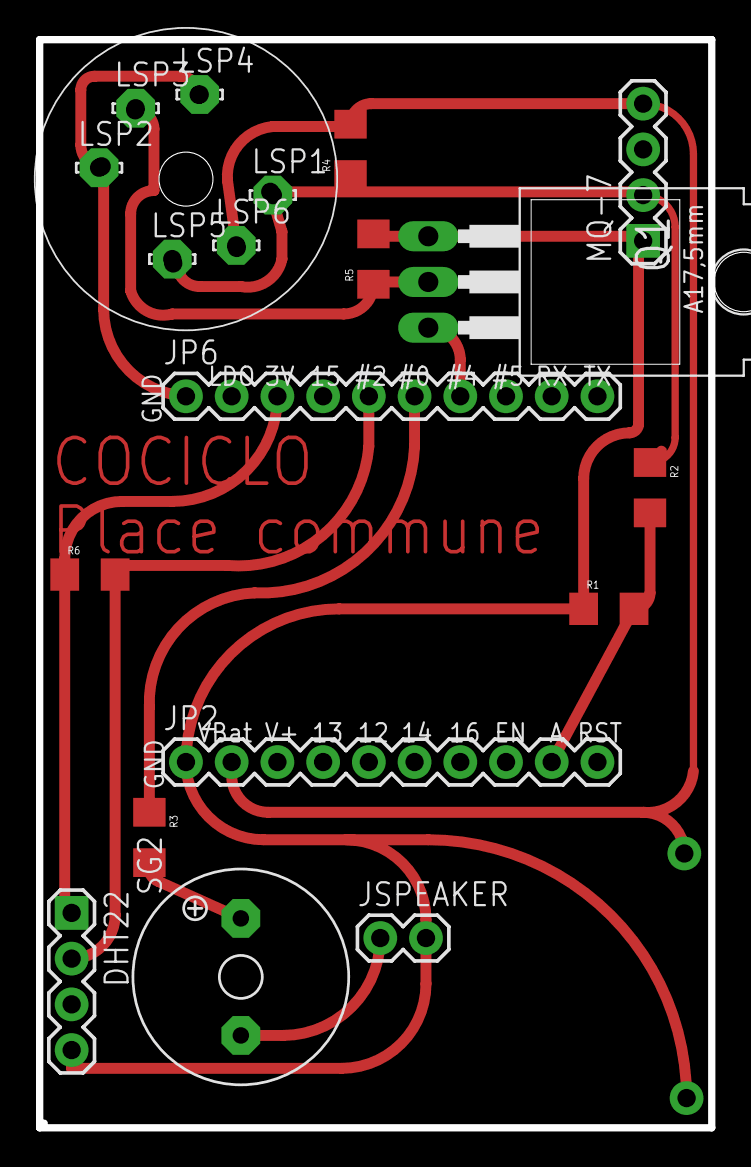
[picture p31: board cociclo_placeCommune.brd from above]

Board: 2 copper layers, 37.3 x 60.5 mm, 23 parts (1 on the bottom side), 12 nets.

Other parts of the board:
U$2: HUZZAHLOGO

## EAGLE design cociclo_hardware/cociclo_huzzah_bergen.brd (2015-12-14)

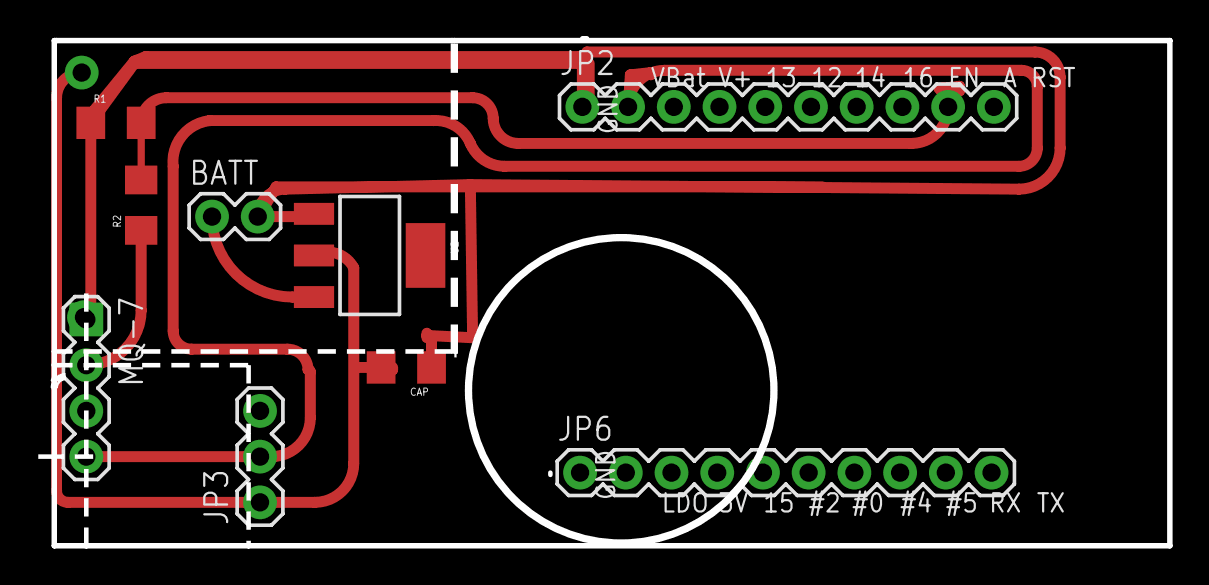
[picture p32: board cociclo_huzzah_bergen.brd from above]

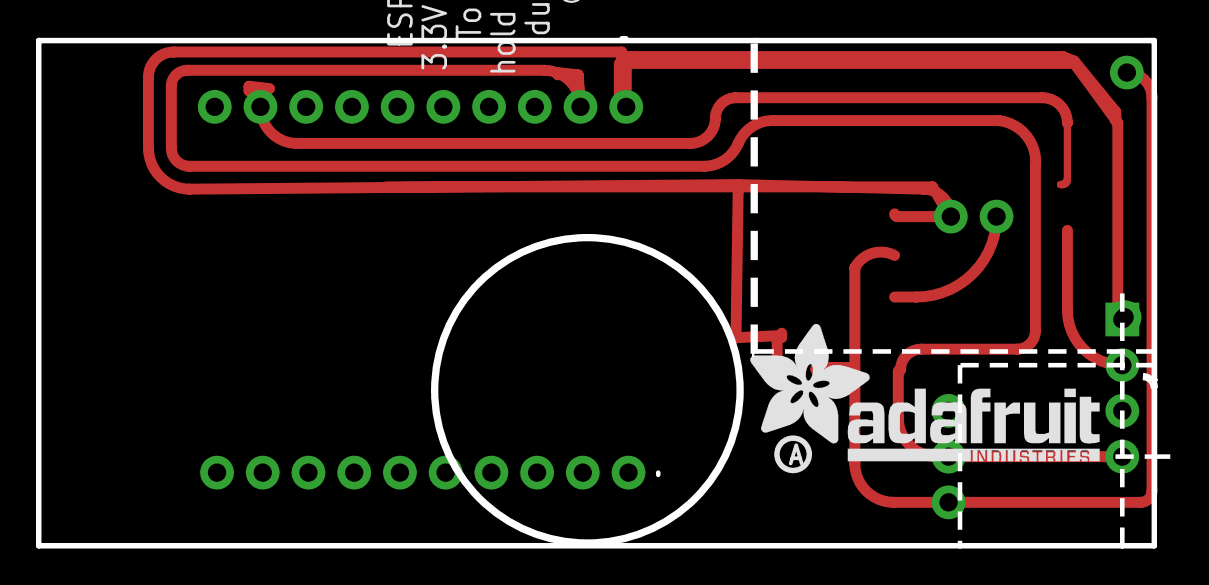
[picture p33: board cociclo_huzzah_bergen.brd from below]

Board: 2 copper layers, 62.9 x 28.2 mm, 14 parts (3 on the bottom side), 6 nets.

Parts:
BATT: 1X02
CAP: 470pf; 1206
JP2, JP6: 1X10
JP3: VIN; 1X03
MQ-7: G A0 D0 V; 1X04
PWR+: VIN; 1X01NS-KIT
PWR-: GND; 1X01NS-KIT
R1: 2k; 1206
R2: 3k; 1206
U2: V_REG_317SMD; SOT223
U$2: HUZZAHLOGO
U$12: ADAFRUIT_TEXT_20MM
U$13: PCBFEAT-REV-040

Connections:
ADC: JP2.9, R1.2, R2.2
GND: BATT.2, JP2.1, JP6.10, MQ-7.1, PWR-.1, R1.1, U2.1
LDO_EN: JP2.2, JP3.2, MQ-7.4
unnamed: MQ-7.2, R2.1
unnamed: JP3.1, PWR+.1, U2.2
unnamed: BATT.1, U2.3

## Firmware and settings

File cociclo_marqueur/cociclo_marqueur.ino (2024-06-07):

/// This part of the project is inspired by the "Dioxygraphe" from Andrew Chartier -> https://esse.ca/portfolio/andrew-chartier/
/// C'est une carte Leonardo
#include <Wire.h>
#include <Adafruit_PWMServoDriver.h>

Adafruit_PWMServoDriver pwm = Adafruit_PWMServoDriver();

#define SERVOMIN  150 // this is the 'minimum' pulse length count (out of 4096)
#define SERVOMAX  600 // this is the 'maximum' pulse length count (out of 4096)

int CO = 0;

  void setup() {
    Serial.begin(9600);
    Serial.println("16 channel Servo test!");
    pwm.begin();
    pwm.setPWMFreq(60);  // Analog servos run at ~60 Hz updates
    }

  void setServoPulse(uint8_t n, double pulse) {
    double pulselength;
  
    pulselength = 1000000;   // 1,000,000 us per second
    pulselength /= 60;   // 60 Hz
    // Serial.print(pulselength); Serial.println(" us per period"); 
    pulselength /= 4096;  // 12 bits of resolution
    // Serial.print(pulselength); Serial.println(" us per bit"); 
    pulse *= 1000;
    pulse /= pulselength;
    //  Serial.println(pulse);
    pwm.setPWM(n, 0, pulse);
    }

  void loop() {
    CO = analogRead(2);
    CO = map(CO,80, 400, 200,666);
    Serial.print("CO : ");
    Serial.println(CO);
    Serial.print("A1 : ");
    Serial.println(analogRead(1));
    Serial.print("A0 : ");
    Serial.println(analogRead(0));
    //geiger(); // il faudrait mettre l'appel aux moteurs dans un interrupt car la vitesse de réponse est trop basse avec geiger()

      if(CO<184 && analogRead(0)<355){  
        masGisBlanca();
        }
        else {
        paraGisBlanca(); 
      }

    if(CO>=184 && analogRead(1)<237){
        masGisAmarilla();
        }
        else {
        paraGisAmarilla();
      }
 
    //delay(200);
    //pwm.setPWM(0, 0, 2000); // premier servo // anti-horaire rapide, 1000 à 450 aussi
    //pwm.setPWM(0,0,320); // horaire lent 
    //pwm.setPWM(1, 0, 430); // anti-horaire lent 400, 390 = jitter
    //Serial.println("recule");
    //delay(5000);
    // pwm.setPWM(0, 0, 400); // horaire lent 370, 200. 100, 50, 10 aussi
    //pwm.setPWM(0, 0, 0); // arrête tout
    Serial.println("------------");
  }

  
  void masGisBlanca(){
    Serial.println("AVANCE BLANC");
    digitalWrite(13, HIGH);
    pwm.setPWM(0, 0, 430); // anti-horaire lent 400, 390 = jitter
    pwm.setPWM(1,0,330); // horaire lent
    delay(100);
    }

  void paraGisBlanca(){ 
    Serial.println("ARRET BLANC");
    pwm.setPWM(0, 0, 0); // stop
    pwm.setPWM(1, 0, 0); // stop
    digitalWrite(13, LOW);
    delay(100);
    }

  void masGisAmarilla(){
    Serial.println("AVANCE Amarilla");
    digitalWrite(12, HIGH);
    pwm.setPWM(2, 0, 430); // anti-horaire lent 400, 390 = jitter
    pwm.setPWM(3,0,330); // horaire lent
    delay(100);
    }

  void paraGisAmarilla(){ 
    Serial.println("ARRET Amarilla");
    pwm.setPWM(2, 0, 0); // stop
    pwm.setPWM(3, 0, 0); // stop
    digitalWrite(12, LOW);
    delay(100);
    }

  void geiger(){
    if (CO < 230)
    {
      tone(5,CO,400); // sortida (PWM), variable, duración del 'pulse'
      delay(50);
      noTone(5);
      delay(500);
      }
      else if (CO >= 230 && CO < 366)
      {
        for (int i=0;i<2;i++)
        {
        tone(5,CO,400); 
        delay(75);
        noTone(5);
        delay(200);
        }
        delay(200);
    }
    else if (CO >= 366 && CO < 666 )
    {
    for (int i=0;i<3;i++)
        {
        tone(5,CO,400);
        delay(65);
        noTone(5);
        delay(80);
              } 
              delay(400);
        }
      else
        {
        tone(5,CO,400); 
        delay(75);
        noTone(5);
        delay(75);
      }
  }

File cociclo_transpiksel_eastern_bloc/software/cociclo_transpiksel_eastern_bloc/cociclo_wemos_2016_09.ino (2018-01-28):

#include <FS.h>                   //this needs to be first, or it all crashes and burns...
#include <ESP8266WiFi.h>          //https://github.com/esp8266/Arduino

//needed for WiFiManager library
#include <DNSServer.h>
#include <ESP8266WebServer.h>
#include <WiFiManager.h>          //https://github.com/tzapu/WiFiManager

#include <ArduinoJson.h>          //https://github.com/bblanchon/ArduinoJson


////////////// Configuration du capteur de température et humidité ////////////
#include "DHT.h"
#define DHTPIN D7     // what digital pin we're connected to the wemos
///#define DHTPIN 2    // what digital pin we're connected to huzzah
#define DHTTYPE DHT11   // DHT 11 (couleur bleue)
////////#define DHTTYPE DHT22   // DHT 22  (AM2302), AM2321

DHT dht(DHTPIN, DHTTYPE);
///////////////////////////////////////////////////////////////////////////////

//////  warm up du capteur ////////
// int lapause = 366600; // 6 minutes, 6 secondes et 6 millièmes de seconde de pause 

int lapause =  1380000;  // 23 minutes x 60 secondes x 1000 millièmes de secondes = 1 380 000) nécessaire pour tous les modèles de capteurs afin d'éviter les fausses lectures.
//int lapause = 0;   // pour tester rapidement

const char* host = "www.cociclo.io"; // le serveur qui reçoit les données

//define your default values here, if there are different values in config.json, they are overwritten.
char ID[30] = "";  /// un tableau de 30 caractères, valeur de cociclo par défaut
char latitude[12] = "";
char longitude[12] = "";

//////////////// Pour obtenir l'adresse MAC ///////////

uint8_t MAC_array[6];  
char MAC_char[18];

//////////// Pour le calcul du maximmum et des moyennes de CO /////

float moyCO;
float maxCO;
int lectures=100;
int i = 0;
float totalCO = 0;

//flag for saving data
bool shouldSaveConfig = false;

//callback notifying us of the need to save config
void saveConfigCallback () {
  Serial.println("Should save config");
  shouldSaveConfig = true;
}

////////////// Neopixel ////////////////////
#include <Adafruit_NeoPixel.h>
#ifdef __AVR__
#include <avr/power.h>
#endif

#define PIN            D2

#define NUMPIXELS      1  /// 4

Adafruit_NeoPixel pixels = Adafruit_NeoPixel(NUMPIXELS, PIN, NEO_GRB + NEO_KHZ800);

int delayval = 750; // delay for half a second

/////////////////////////////////////////


void setup() {
   pixels.begin(); // This initializes the NeoPixel library.
  
  Serial.begin(115200);
  delay(100);
  
  Serial.println();

//clean FS, for testing ////// CUIDADO  ///////
// SPIFFS.format();
//////////////////////////////

  //read configuration from FS json
  Serial.println("mounting FS...");
  

  if (SPIFFS.begin()) {
    Serial.println("mounted file system");
    if (SPIFFS.exists("/config.json")) {
      //file exists, reading and loading
      Serial.println("reading config file");
      File configFile = SPIFFS.open("/config.json", "r");
      if (configFile) {
        Serial.println("opened config file");
        size_t size = configFile.size();
        // Allocate a buffer to store contents of the file.
        std::unique_ptr<char[]> buf(new char[size]);

        configFile.readBytes(buf.get(), size);
        DynamicJsonBuffer jsonBuffer;
        JsonObject& json = jsonBuffer.parseObject(buf.get());
        json.printTo(Serial);
        if (json.success()) {
          Serial.println("\nparsed json");


       strcpy(ID, json["ID"]);
       strcpy(latitude, json["latitude"]);
       strcpy(longitude, json["longitude"]);

        } else {
          Serial.println("failed to load json config");
        }
      }
    }
  } else {
    Serial.println("failed to mount FS");
  }
  //end read

  

///////////// Print de l'adresse MAC

WiFi.macAddress(MAC_array);
    for (int i = 0; i < sizeof(MAC_array); ++i){
      sprintf(MAC_char,"%s%02x:",MAC_char,MAC_array[i]);
    }
  
    Serial.println(MAC_char);

  /////////////////////////////////////////////
  // The extra parameters to be configured (can be either global or just in the setup)
  // After connecting, parameter.getValue() will get you the configured value
  // id/name placeholder/prompt default length

  WiFiManagerParameter custom_ID("ID", "ID", ID, 30);
  WiFiManagerParameter custom_latitude("latitude", "latitude", latitude, 12);
  WiFiManagerParameter custom_longitude("longitude", "longitude", longitude, 12);
  

  //WiFiManager
  //Local intialization. Once its business is done, there is no need to keep it around
  WiFiManager wifiManager;

  //set config save notify callback
  wifiManager.setSaveConfigCallback(saveConfigCallback);

  //set static ip
  // wifiManager.setSTAStaticIPConfig(IPAddress(10,0,1,99), IPAddress(10,0,1,1), IPAddress(255,255,255,0));
  
  //add all your parameters here
  wifiManager.addParameter(&custom_ID);
  wifiManager.addParameter(&custom_latitude);
  wifiManager.addParameter(&custom_longitude);

 ////// pas de serveur /////
 Serial.println("indication couleur");
  pixels.setPixelColor(0, pixels.Color(10,10,255)); // azul
   pixels.show(); // This sends the updated pixel color to the hardware.

   delay(1000);
     pixels.setPixelColor(0, pixels.Color(10,10,150)); // azul
   pixels.show(); // This sends the updated pixel color to the hardware.

delay(1000);
/*
   pixels.setPixelColor(1, pixels.Color(150,10,150)); // azul
   pixels.show(); // This sends the updated pixel color to the hardware.

  
delay(1000); 

  pixels.setPixelColor(2, pixels.Color(150,150,10)); // azul
   pixels.show(); // This sends the updated pixel color to the hardware.

  
delay(1000);

 pixels.setPixelColor(3, pixels.Color(100,50,150)); // azul
   pixels.show(); // This sends the updated pixel color to the hardware.
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

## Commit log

2015-06-10 Commit del Noviembre 2014 taller en Cali
    Beta version! Contact me if you would like to build one.
    [boitier_01_base.skp, boitier_01_couvercle.skp, cociclo.fzz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]
2015-07-20 cordova android project
    This version reads in audio frequencies and displays geolocation
    information. Works for android atm, let me know if you’d like to test
    for iOS.
2015-09-22 Many changes, the hardware part got simpler and the code got more complex.
    The chain from sensor to server functions!
2015-09-23 Explicaciones y el código Arduino
2015-09-24 archive pour android México et petite correction de commentaire
    [Mexico_COciclo.ino]
2015-11-21 Piksel Bergen Version
    Switching to UDP over wifi and a design with the huzzah.
2015-12-14 petit changement pour la version de Bergen
2015-12-14 Huzzah version
    Version de Arles, fonctionne avec le esp8266.
    [BOM.ods, boitier_01_base.skp, boitier_01_couvercle.skp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]
2016-04-01 Cociclo PlaceCommune
    Tout le nécessaire pour la version 'base' du Cociclo.
    [cociclo_2016_BOM.xlsx, cociclo_placeCommune.brd, cociclo_placeCommune.sch]
2016-04-01 Ajout du coût des plaquettes et DHT
    Le coût réel des plaquettes et des capteurs de température + humidité
    [cociclo_2016_BOM.xlsx]
2016-04-02 Infos sur les composantes
    Ajout des valeurs des résistances et des connexions.
2016-04-02 Sensors
    Les capteurs MQ7 (monoxyde de carbone) et DHT11 (Température et humidité) (équivalent au DHT22)
2016-04-02 MQ7
    Avec les valeurs de ses broches.
2016-04-02 MQ7 de sainsmart
    ...la bonne version!
2016-04-05 sélection des utilisateurs depuis la bd
    + Ajout d'un menu pour la sélection des utilisateurs lors de la sélection des données. CO.php fait un appel à la base de données via un argument d'URL à conversion.php
    + Un peu de ménage avec un .css
    + Des essais de logos
    = doit ajouter un champ pour l'adresse MAC du esp8266 afin de distinguer les utilisateurs
    = doit modifier le code Arduino pour le recueillir et aussi proposer un
    = doit réduire la fréquence d'envois (passer de 7 secondes à un par minute) à la base de données et prévoir une moyenne glissante
2016-04-20 Update connect2.php
    Est-ce qu'il serait possible de faire une vérification sur la 'MAC address' de chaque cociclo? Parce que c'est maintenant la première donnée envoyée. Ça serait super sécur? Les types des données sont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
2016-04-20 Update cociclo_placeCommune.ino
    Ajout de la 'MAC address', de la moyenne et des valeurs maximales. Pour augmenter le délai entre les écritures dans la base de données, simplement augmentez la valeur de la variable 'lecture'.
    Added polling for the MAC Address, a means and a maximum for the CO readings. Increase the value of 'lectures' in order to augment the delay between writes to the database.
    Merci Wassim!
2016-05-03 Howto solder the board
2016-08-16 versión para wemos, estación y portable
    [cociclo_transpiksel_2016_BOM.xlsx, cociclo_wemos_2016_final_2.brd, cociclo_wemos_2016_final_2.sch]
2016-08-29 Update connect2.php
    mise à jour de la structure de la base de donnée par création d'une table par utilisateur
2016-09-01 3D models for the base station
    [radome avec base.stl, radome.stl]
2016-09-01 Infos sobre el taller
2016-09-01 gcode para una DittoPRO (1,75mm filament)
2016-09-08 para la calibración
2016-10-08 Delay value set to 20 minutes for the sensor burn-in
    [cociclo_wemos_2016_09.ino]
2018-01-28 old code + files
    [EnregistrementAuto_cociclo_fond.skp, cociclo_2016_BOM.xlsx, cociclo_fond.skp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]
2018-01-28 version 03
    + Plantones PMS3003 gracias unloquer
    + Dotstar SK9822 RGB LED
    [cociclo_03.brd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]
2018-01-28 cociclo v3 BOM
    [cociclo_03_BOM.xlsx]
2018-01-29 PMS3003 works!
    Next step is to integrate everything in the main code
    [cociclo_03_BOM.xlsx]
2018-10-10 From december 2017!
    TODO : add the Plantower sensor, automatic geolocation
2018-10-10 début de la version 05 et fichiers grb
    [cociclo_03_01.brd, cociclo_03_01.sch, cociclo_04.brd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]
2018-10-15 intégration du PMS300 refactorisation du code
    peut maintenant détecter la pollution par les particules
    auto détecte la localisation
2018-10-19 listos!
    intégration de la routine de géolocalisation
    de l’indication avec la DEL dotstar
    et avec le script PHP d’écriture dans la base de données
2018-11-08 hasta la 1.0 :)
    Adición logo unloquer
    Adición opción para Adafruit MAX 4466
    Adición ‘screw terminal’
    [cociclo_05.sch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]
2019-02-26 commit
    a typeDonnees field to distinguish the type of data collected
    [cociclo_05.brd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]
2019-06-05 test pour les DEls dotstar
    ouin

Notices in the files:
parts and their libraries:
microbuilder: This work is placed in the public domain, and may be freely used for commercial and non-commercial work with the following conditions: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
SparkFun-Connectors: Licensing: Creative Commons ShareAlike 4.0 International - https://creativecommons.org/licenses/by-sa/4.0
